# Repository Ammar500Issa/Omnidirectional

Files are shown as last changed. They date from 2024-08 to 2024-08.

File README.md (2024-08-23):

# Omnidirectional Mobile Robot

## Project Description
This project involves the design, simulation, and control of a four-wheeled omnidirectional mobile robot capable of catching a thrown ball. The robot was manufactured using Nema 23 stepper motors, optical encoders, and an Arduino Mega 2560. A camera is used in conjunction with computer vision and the Extended Kalman Filter (EKF) algorithm to estimate the robot’s position and orientation. The project includes a Sliding Mode Controller and a simulation environment in PyBullet.

## Key Features
- Omnidirectional robot capable of catching a ball
- Extended Kalman Filter for real-time position estimation
- Sliding Mode Controller
- Simulation in PyBullet and MATLAB
- Real-time control using Arduino

## Technologies Used
- Arduino Mega 2560
- Python (PyBullet, OpenCV)
- MATLAB
- Stepper Motors and Optical Encoders

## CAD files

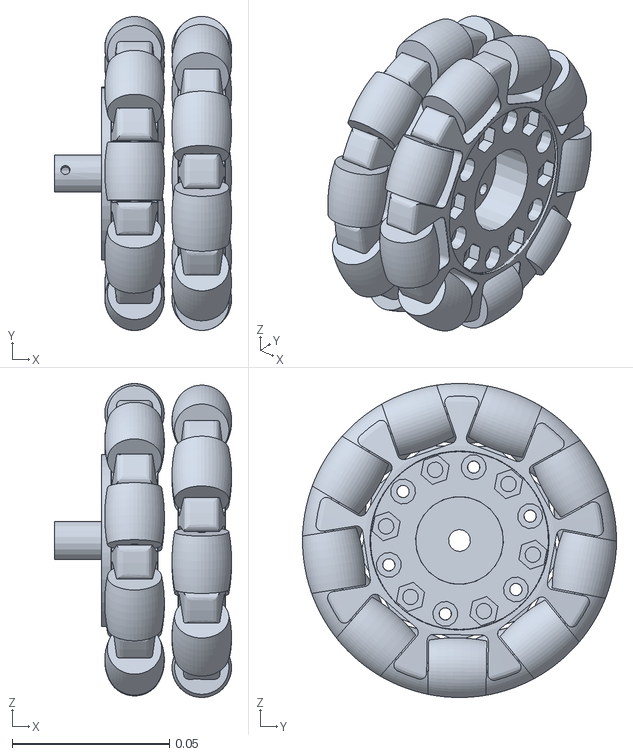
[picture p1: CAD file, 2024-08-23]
Omnidirectional Mobile Robot/Omnidirectional/Robot/meshes/wheel_three.STL
0.0564 x 0.1 x 0.1

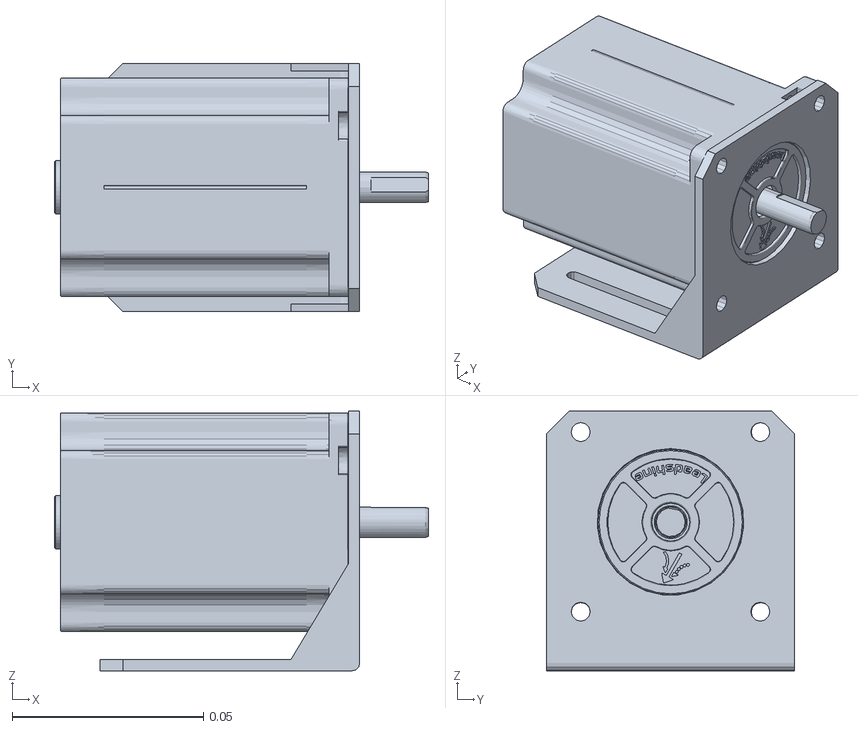
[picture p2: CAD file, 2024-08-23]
Omnidirectional Mobile Robot/Omnidirectional/Robot/meshes/motor_four.STL
0.0979 x 0.065 x 0.068

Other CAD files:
Omnidirectional Mobile Robot/Omnidirectional/Robot/meshes/wheel_four.STL
Omnidirectional Mobile Robot/Omnidirectional/Robot/meshes/wheel_one.STL
Omnidirectional Mobile Robot/Omnidirectional/Robot/meshes/motor_three.STL
Omnidirectional Mobile Robot/Omnidirectional/Robot/meshes/motor_two.STL
Omnidirectional Mobile Robot/Omnidirectional/Robot/meshes/wheel_two.STL
Omnidirectional Mobile Robot/Omnidirectional/Robot/meshes/motor_one.STL

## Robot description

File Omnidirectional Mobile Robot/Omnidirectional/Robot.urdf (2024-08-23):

<?xml version="1.0" encoding="utf-8"?>
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
<robot name="Robot">
  <link name="base_link">
    <inertial>
      <origin xyz="-0.157486061036765 -0.000285085739825081 -0.0225046964819652" rpy="0 0 0" />
      <mass value="1.206753271021" />
      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
    </inertial>
    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
  </link>
  <link name="motor_one">
    <inertial>
      <origin xyz="-0.0130082713947478 -0.00764575523290381 -0.0609808542253382" rpy="0 0 0" />
      <mass value="1.1" />
      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
    </inertial>
    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
  </link>
  <joint name="base_motor_one" type="fixed">
    <origin xyz="0.00119745896918461 0 -0.03" rpy="0 0 0" />
    <parent link="base_link" />
    <child link="motor_one" />
    <axis xyz="0 0 0" />
  </joint>
  <link name="wheel_one">
    <inertial>
      <origin xyz="0.027605 1.3484E-05 6.9609E-05" rpy="0 0 0" />
      <mass value="0.19596" />
      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
    </inertial>
    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
  </link>
  <joint name="joint_one" type="continuous">
    <origin xyz="0.03355 -0.0076435 -0.05714" rpy="0 0 0" />
    <parent link="motor_one" />
    <child link="wheel_one" />
    <axis xyz="1 0 0" />
  </joint>
  <link name="motor_two">
    <inertial>
      <origin xyz="-0.0130082713947483 -0.00764575523290717 -0.0609808542253383" rpy="0 0 0" />
      <mass value="1.1" />
      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
    </inertial>
    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
  </link>
  <joint name="base_motor_two" type="fixed">
    <origin xyz="-0.16 0.1612 -0.03" rpy="0 0 1.5708" />
    <parent link="base_link" />
    <child link="motor_two" />
    <axis xyz="0 0 0" />
  </joint>
  <link name="wheel_two">
    <inertial>
      <origin xyz="0.027605 1.3484E-05 6.9609E-05" rpy="0 0 0" />
      <mass value="0.19596" />
      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
    </inertial>
    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
  </link>
  <joint name="joint_two" type="continuous">
    <origin xyz="0.03355 -0.0076435 -0.05714" rpy="0 0 0" />
    <parent link="motor_two" />
    <child link="wheel_two" />
    <axis xyz="1 0 0" />
  </joint>
  <link name="motor_three">
    <inertial>
      <origin xyz="-0.0130082713947506 0.00835424476709146 -0.0609808542253382" rpy="0 0 0" />
      <mass value="1.1" />
      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
    </inertial>
    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
  </link>
  <joint name="base_motor_three" type="fixed">
    <origin xyz="-0.3212 0 -0.03" rpy="0 0 3.1416" />
    <parent link="base_link" />
    <child link="motor_three" />
    <axis xyz="0 0 0" />
  </joint>
  <link name="wheel_three">
    <inertial>
      <origin xyz="0.027605 1.3484E-05 6.9609E-05" rpy="0 0 0" />
      <mass value="0.19596" />
      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
    </inertial>
    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
  </link>
  <joint name="joint_three" type="continuous">
    <origin xyz="0.03355 0.0083565 -0.05714" rpy="0 0 0" />
    <parent link="motor_three" />
    <child link="wheel_three" />
    <axis xyz="1 0 0" />
  </joint>
  <link name="motor_four">
    <inertial>
      <origin xyz="-0.013008 0.0077542 -0.060981" rpy="0 0 0" />
      <mass value="1.1" />
      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
    </inertial>
    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
  </link>
  <joint name="base_motor_four" type="fixed">
    <origin xyz="-0.160000000000001 -0.161197458969184 -0.0299999999999984" rpy="0 0 -1.5707963267949" />
    <parent link="base_link" />
    <child link="motor_four" />
    <axis xyz="0 0 0" />
  </joint>
  <link name="wheel_four">
    <inertial>
      <origin xyz="0.027605 1.3484E-05 6.9609E-05" rpy="0 0 0" />
      <mass value="0.19596" />
      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
    </inertial>
    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
  </link>
  <joint name="joint_four" type="continuous">
    <origin xyz="0.03355 0.0077565 -0.05714" rpy="0 0 0" />
    <parent link="motor_four" />
    <child link="wheel_four" />
    <axis xyz="1 0 0" />
  </joint>
</robot>

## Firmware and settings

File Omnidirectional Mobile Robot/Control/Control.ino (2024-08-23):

#include <AccelStepper.h>
#include <MultiStepper.h>
#include <TimerOne.h>

AccelStepper S1(1, 8, 7);
AccelStepper S2(1, 10, 4);
AccelStepper S3(1, 9, 5);
AccelStepper S4(1, 11, 6);
MultiStepper S;

#define encPin1 19
#define encPin2 2
#define encPin3 3
#define encPin4 18

double r = 0.05; // Radius of the wheel
double L = 0.15; // Distance between the center of the robot and each wheel
double Bv = 0.038709; // Dynamic friction coefficient of linear transition
double Bw = 0.0008517; // Dynamic friction coefficient of angular rotation
double Cv = 0.019178; // Static friction coefficient of linear transition
double Cw = 0.099875; // Static friction coefficient of angular rotation
//double Bv = 0.5;
//double Bw = 0;
//double Cv = 2;
//double Cw = 0;
double J = 0.45923; // Inertia of the robot
double M = 9.1; // Mass of the robot
double mu_p = 0;
double g = 9.81;
// uncertainities
double dBv = 0.001; // Errors
double dCv = 0.001;
double dBw = 0.0001;
double dCw = 0.01;
//double dBv = 0;
//double dCv = 0;
//double dBw = 0;
//double dCw = 0;

// Controller coefficients
double lambda1 = 2.75;
double lambda2 = 2.75;
double lambda3 = 5;
double eta1 = 1;
double eta2 = 1;
double eta3 = 1;
double K1 = 2.5;
double K2 = 2.5;
double K3 = 20;

int dir1 = 0;
int dir2 = 0;
int dir3 = 0;
int dir4 = 0;

double T = 0.01;
unsigned long previousMicros = 0;

// encoders
volatile double pos1 = 0;
volatile double pos2 = 0;
volatile double pos3 = 0;
volatile double pos4 = 0;

double lastPos1 = 0;
double lastPos2 = 0;
double lastPos3 = 0;
double lastPos4 = 0;
double lastTheta = 0;
double lastX = 0;
double lastY = 0;
double Xd = 0.7;
double Yd = 0;
double lastFreq1 = 0;
double lastFreq2 = 0;
double lastFreq3 = 0;
double lastFreq4 = 0;

// From camera (using serial connection)
float XC = 0;
float YC = 0;
float ThetaC = 0;

void setup()
{  
  Serial.begin(115200);
  S1.setMaxSpeed(5000);
  S2.setMaxSpeed(5000);
  S3.setMaxSpeed(5000);
  S4.setMaxSpeed(5000);
  S1.setAcceleration(5000);
  S2.setAcceleration(5000);
  S3.setAcceleration(5000);
  S4.setAcceleration(5000);
//  S.addStepper(S1);
//  S.addStepper(S2);
//  S.addStepper(S3);
//  S.addStepper(S4);
  pinMode(encPin1, INPUT_PULLUP);
  pinMode(encPin2, INPUT_PULLUP);
  pinMode(encPin3, INPUT_PULLUP);
  pinMode(encPin4, INPUT_PULLUP);
  attachInterrupt(digitalPinToInterrupt(encPin1), encoder1Interrupt, CHANGE);
  attachInterrupt(digitalPinToInterrupt(encPin2), encoder2Interrupt, CHANGE);
  attachInterrupt(digitalPinToInterrupt(encPin3), encoder3Interrupt, CHANGE);
  attachInterrupt(digitalPinToInterrupt(encPin4), encoder4Interrupt, CHANGE);
//  delay(10000);
  Timer1.initialize(1000000*T); // set timer to T seconds
  Timer1.attachInterrupt(timerISR);
  sei();
}

void encoder1Interrupt() {
  if(dir1 > 0)
    pos1 += TWO_PI/2048.0;
  else if(dir1 < 0)
    pos1 -= TWO_PI/2048.0;
}

void encoder2Interrupt() {
  if(dir2 > 0)
    pos2 += TWO_PI/2048.0;
  else if(dir2 < 0)
    pos2 -= TWO_PI/2048.0;
}

void encoder3Interrupt() {
  if(dir3 > 0)
    pos3 += TWO_PI/2048.0;
  else if(dir3 < 0)
    pos3 -= TWO_PI/2048.0;
}

void encoder4Interrupt() {
  if(dir4 > 0)
    pos4 += TWO_PI/2048.0;
  else if(dir4 < 0)
    pos4 -= TWO_PI/2048.0;
}

void InvKinematic(double w[], double V[]) { //w: rad/sec. V[0], V[1]: m/sec. V[2]: rad/sec.
  w[0] = 1/r*(V[1] + L*V[2]);
  w[1] = 1/r*(-V[0] + L*V[2]);
  w[2] = 1/r*(-V[1] + L*V[2]);
  w[3] = 1/r*(V[0] + L*V[2]);
}

int sign(double X) {
  if(X > 0) {
    return 1;
  }
  else if(X < 0) {
    return -1;
  }
  else
    return 0;
}

double sat(double X) { // Replacing the sign function with saturation to avoid high frequency changes
  double Y_sat = 1;
  double X_sat = 0.1;
  if(X > X_sat) {
    return 1;
  }
  else if(X < -X_sat) {
    return -1;
  }
  else
    return X*Y_sat/X_sat;
}

void timerISR() 
{
    double w[4];
    w[0] = (pos1 - lastPos1)/T;
    w[1] = (pos2 - lastPos2)/T;
    w[2] = (pos3 - lastPos3)/T;
    w[3] = (pos4 - lastPos4)/T;
//    w[0] = lastFreq1;
//    w[1] = lastFreq2;
//    w[2] = lastFreq3;
//    w[3] = lastFreq4;
    lastPos1 = pos1;
    lastPos2 = pos2;
    lastPos3 = pos3;
    lastPos4 = pos4;
    double Vxb = 0.5*r*(w[3] - w[1]);
    double Vyb = 0.5*r*(w[0] - w[2]);
    double dTheta = 0.25*r/L*(w[0] + w[1] + w[2] + w[3]);
    double Theta = dTheta*T + lastTheta;
    if(Theta > PI) {
      Theta -= TWO_PI;
    }
    else if(Theta < -PI) {
      Theta += TWO_PI;
    }
//    Theta = ThetaC;
    lastTheta = Theta;
    double Vx = cos(Theta)*Vxb - sin(Theta)*Vyb; // Converting between coordinate systems
    double Vy = cos(Theta)*Vyb + sin(Theta)*Vxb;
    double X = Vx*T + lastX;
    double Y = Vy*T + lastY;
//    X = XC;
//    Y = YC;
    Vx = (X - lastX)/T;
    Vy = (Y - lastY)/T;
    dTheta = (Theta - lastTheta)/T;
    lastX = X;
    lastY = Y;
    double ex = X - Xd;
    double ey = Y - Yd;
  // Setting the controller commands
    double u[4];
    u[0] = (1/(r*M))*(Bv*Vy + Cv*sign(Vy)) - (lambda2/r)*Vy;
    u[2] = -u[0];
    u[3] = (1/(r*M))*(Bv*Vx + Cv*sign(Vx)) - (lambda1/r)*Vx;
    u[1] = -u[3];
    double uy = -(K2/r)*(eta2 + (dBv/M)*abs(Vy) + dCv/M + mu_p*g)*sat(Vy + lambda2*ey);
    double ux = -(K1/r)*(eta1 + (dBv/M)*abs(Vx) + dCv/M + mu_p*g)*sat(Vx + lambda1*ex);
    u[0] += uy;
    u[2] -= uy;
    u[1] -= ux;
    u[3] += ux;
    double uTheta = 1/(2*L*M*r)*((Bw - J*lambda3)*dTheta + Cw*sign(dTheta) - K3*(J*eta3 + dBw*abs(dTheta) + dCw + L*M*mu_p*g)*sign(dTheta + lambda3*Theta));
    u[0] += uTheta;
    u[1] += uTheta;
    u[2] += uTheta;
    u[3] += uTheta;
    double f[4];
    f[0] = u[0]*T + lastFreq1;
    f[1] = u[1]*T + lastFreq2;
    f[2] = u[2]*T + lastFreq3;
    f[3] = u[3]*T + lastFreq4;
    lastFreq1 = f[0];
    lastFreq2 = f[1];
    lastFreq3 = f[2];
    lastFreq4 = f[3];
    S1.setSpeed(f[0]*100/PI);
    S2.setSpeed(f[1]*100/PI);
    S3.setSpeed(f[2]*100/PI);
    S4.setSpeed(f[3]*100/PI);
    dir1 = sign(f[0]);
    dir2 = sign(f[1]);
    dir3 = sign(f[2]);
    dir4 = sign(f[3]);
    double s[8];
    s[0] = u[0];
    s[1] = u[1];
    s[2] = u[2];
    s[3] = u[3];
    s[4] = w[0];
    s[5] = w[1];
    s[6] = w[2];
    s[7] = w[3];
    String str1;
    String str2;
    String str3;
    String str4;
    String str5;
    String str6;
    String str7;
    String str8;
    char str[100] = "";
    strcat(str, "%");
    for (int i = 0; i < 8; i++) {
      char temp[10];
      dtostrf(s[i], 5, 2, temp); // convert double to string with sign and 2 decimal points
      strcat(str, temp); // concatenate string
      if (i < 7) { // add "#" between values except for the last one
        strcat(str, "#");
      }
    }
    strcat(str, "%");
}

void loop()
{
  if (Serial.available() >= 12) {
    byte buffer[12];
    Serial.readBytes(buffer, 12);
    memcpy(&XC, &buffer[0], 4);
    memcpy(&YC, &buffer[4], 4);
    memcpy(&ThetaC, &buffer[8], 4);
    Serial.print("X: ");
    Serial.println(XC);
    Serial.print("Y: ");
    Serial.println(YC);
    Serial.print("Theta: ");
    Serial.println(ThetaC);
  }
  unsigned long currentMicros = micros();
  S1.run();
  S2.run();
  S3.run();
  S4.run();
}

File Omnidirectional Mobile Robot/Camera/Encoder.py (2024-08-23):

with open('Encoder.txt', 'r') as f:
    lines = f.readlines()
i = 0
n = 1790
g1 = open('X.txt', 'a')
g2 = open('Y.txt', 'a')
g3 = open('Theta.txt', 'a')
g4 = open('Vx.txt', 'a')
g5 = open('Vy.txt', 'a')
g6 = open('w.txt', 'a')
g7 = open('u1.txt', 'a')
g8 = open('u2.txt', 'a')
g9 = open('u3.txt', 'a')
g10 = open('u4.txt', 'a')
while i < n:
    data = lines[i].split()
    g1.write(data[0][:-1])
    g1.write('\n')
    # g1.close()
    
    g2.write(data[1][:-1])
    g2.write('\n')
    # g2.close()
    
    g3.write(data[2][:-1])
    g3.write('\n')
    # g3.close()
    
    g4.write(data[3][:-1])
    g4.write('\n')
    # g4.close()
    
    g5.write(data[4][:-1])
    g5.write('\n')
    # g5.close()

    g6.write(data[5][:-1])
    g6.write('\n')
    # g2.close()
    
    g7.write(data[6][:-1])
    g7.write('\n')
    # g3.close()
    
    g8.write(data[7][:-1])
    g8.write('\n')
    # g4.close()
    
    g9.write(data[8][:-1])
    g9.write('\n')
    # g5.close()

    g10.write(data[9][:-1])
    g10.write('\n')
    # g5.close()
    i = i + 1

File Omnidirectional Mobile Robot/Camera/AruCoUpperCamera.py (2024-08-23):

# This code is used to detect the position (x, y) and orientation (theta) of the robot using a calibrated external upper camera, and is used to test and estimate the robot's parameters
import numpy as np
import cv2
import requests
import yaml
import cv2.aruco
from time import time
import serial
import struct
from time import sleep

with open("Calibration.yml", 'r') as stream:
    dictionary = yaml.safe_load(stream)
C = dictionary.get("camera_matrix")
Dist = dictionary.get("dist_coeff")

filename = "C:\\Users\\Ammar Issa\\Downloads\\Project\\" + "CameraXYTheta" + ".mat"
# ser = serial.Serial('COM16', 115200)

cap = cv2.VideoCapture(0)
# cap = cv2.VideoCapture('1.mp4')
i = 0

cap.set(cv2.CAP_PROP_FPS, 30)
cap.set(cv2.CAP_PROP_FRAME_WIDTH, 1024)
cap.set(cv2.CAP_PROP_FRAME_HEIGHT, 576)
# ret, img = cap.read()
# filename = "C:\\Users\\Ammar Issa\\Desktop\\Camera\\" + "Potato" + ".jpg"
# cv2.imwrite(filename, img)

g1 = open('X.txt', 'a') # These files are used to save the position and orientation of the robot at each moment
g2 = open('Y.txt', 'a')
g3 = open('Theta.txt', 'a')

lastPos = [-1, -1]
lastTheta = -1
lastVec = [-1, -1]
lastHor = [-1, -1]

t1 = time()
while True:
    i += 1
    ret, img = cap.read()
    dictionary = cv2.aruco.getPredefinedDictionary(cv2.aruco.DICT_4X4_50)
    parameters = cv2.aruco.DetectorParameters()
    detector = cv2.aruco.ArucoDetector(dictionary, parameters) # Detecting the AruCo marker placed on the top of the robot
    markerCorners, markerIds, rejectedCandidates = detector.detectMarkers(img)
    if markerIds is None:
        pos = lastPos
        theta = lastTheta
        vec = lastVec
        hor = lastHor
    else:
        pos = np.mean(markerCorners, axis = 0)
        pos = np.mean(pos, axis = 0)
        pos = np.mean(pos, axis = 0)
        vec = np.mean(markerCorners, axis = 0)
        vec = np.mean(vec, axis = 0)
        vec = np.mean(vec[0:2], axis = 0)
        vecLen = np.sqrt(vec[0] ** 2 + vec[1] ** 2)
        vec = vec - pos
        hor = [vecLen, pos[1]] - pos
        theta = np.dot(vec, hor)/(np.sqrt(vec[0] ** 2 + vec[1] ** 2)*np.sqrt(hor[0] ** 2 + hor[1] ** 2))
        theta = np.arccos(theta)
        lastPos = pos
        lastTheta = theta
        lastVec = vec
        lastHor = hor
    data = bytearray(struct.pack("fff", pos[0]*0.1/71 - 0.7566901408450705, -pos[1]*0.1/60 + 0.3408333333333334, theta))
    with open(filename, 'w') as f:
        f.write(str(pos[0]*0.1/71 - 0.7566901408450705) + "\n" + str(-pos[1]*0.1/60 + 0.3408333333333334) + "\n" + str(theta))
    # The following lines are used to write the data into external files for other use
    # sleep(0.05)
    # ser.write(data)
    # print(str(pos[0]*0.1/71 - 0.7566901408450705) + " " + str(-pos[1]*0.1/60 + 0.3408333333333334) + " " + str(theta))
    # print(data)
    # cv2.circle(img, (int(pos[0]), int(pos[1])), 4, (0, 0, 255), -1)
    # cv2.circle(img, (int(vec[0] + pos[0]), int(vec[1] + pos[1])), 4, (0, 0, 255), -1)
    # cv2.line(img, (int(pos[0]), int(pos[1])), ((int(vec[0] + pos[0])), int(vec[1] + pos[1])), (255, 0, 0), 2)
    # cv2.circle(img, (int(hor[0] + pos[0]), int(hor[1] + pos[1])), 4, (0, 0, 255), -1)
    # cv2.line(img, (int(pos[0]), int(pos[1])), ((int(hor[0] + pos[0])), int(hor[1] + pos[1])), (255, 0, 0), 2)
    # cv2.imshow("image", img)
    # filename = "C:\\Users\\Ammar Issa\\Desktop\\Camera\\Moving Ball\\" + str(i) + ".jpg"
    # cv2.imwrite(filename, img)
    # g1.write(str(pos[0]))
    # g1.write('\n')
    # g2.write(str(pos[1]))
    # g2.write('\n')
    # g3.write(str(theta))
    # g3.write('\n')
    # cv2.waitKey(1)
    # if cv2.waitKey(1) == 27:
    #     break
t2 = time()
print(200/(t2 - t1))
cv2.destroyAllWindows()
